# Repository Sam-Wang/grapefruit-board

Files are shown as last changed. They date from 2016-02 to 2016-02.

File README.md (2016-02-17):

uMeshFw Grapefruit board / debug platform
==============================================

During the last two years of sparse uMeshFw development I noticed that often a problem or a feature
cannot be properly simulated and tested. Most of the development was done on a qNode4 platform,
which (among the others) lacks support for many required peripherals and is not very debug-friendly.
It was (and still is) meant to be used in "production".

Therefore I decided to specify a new debug board / platform which should ease the development
of the uMeshFw firmware and uMesh protocol stack features.

Also, I had a feeling that qNodeX names are a bit boring.

This repository is a Work in Progress and is still incomplete. Full project description can be
found on the [project page](http://qyx.krtko.org/projects/umeshfw-grapefruit-board/)

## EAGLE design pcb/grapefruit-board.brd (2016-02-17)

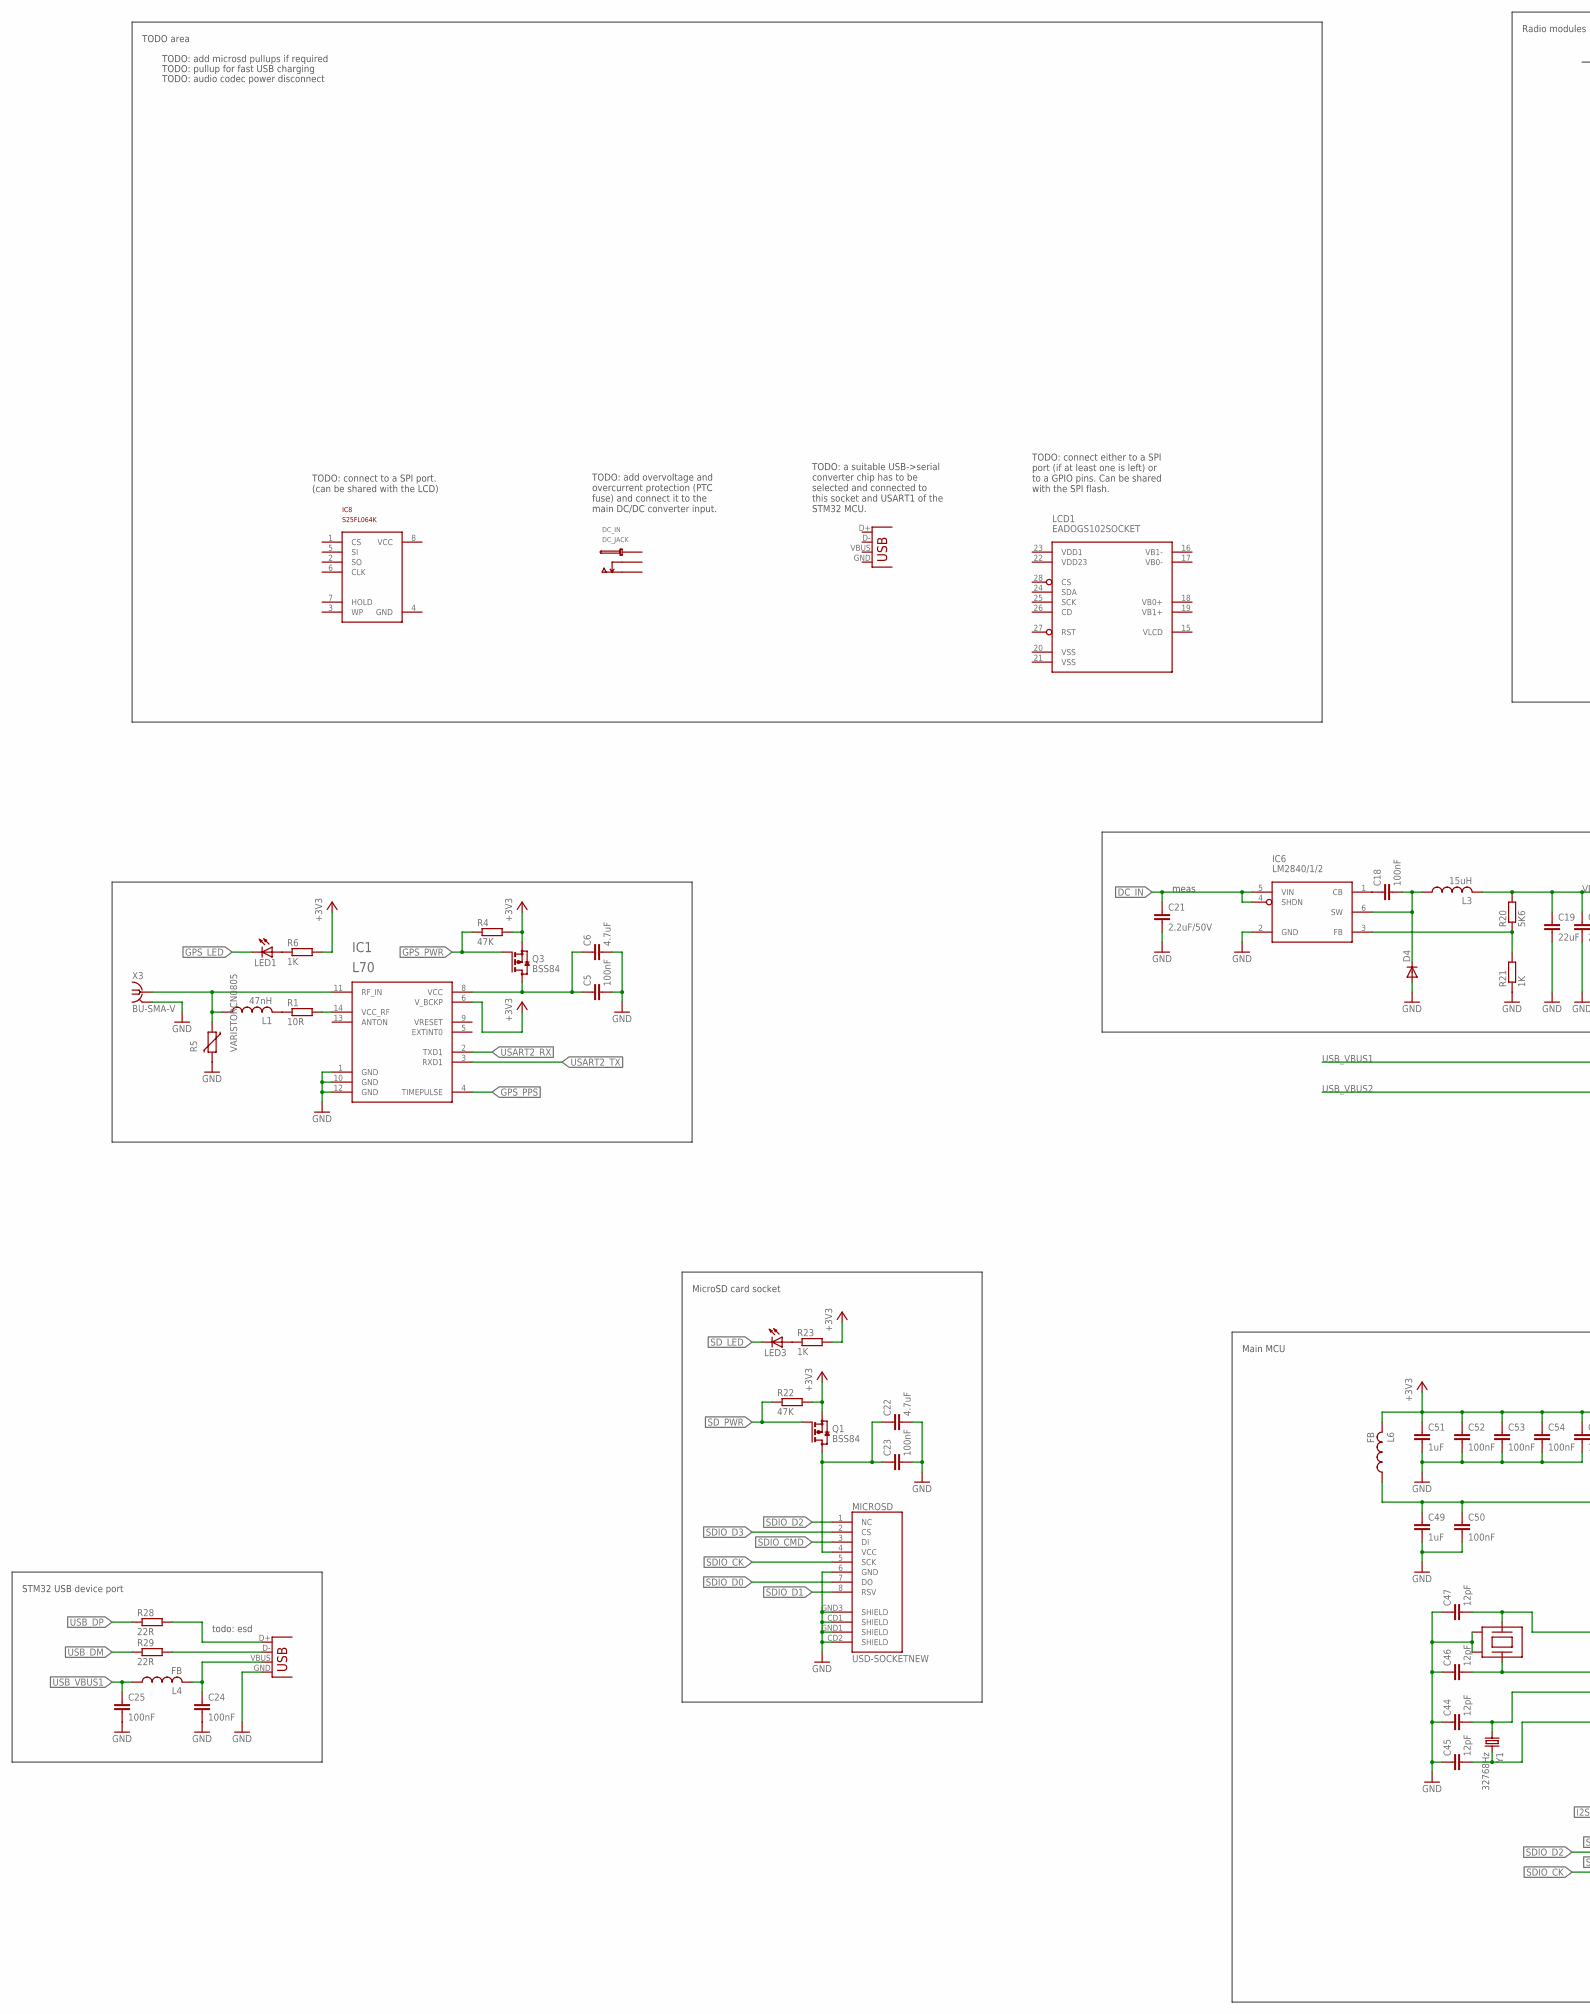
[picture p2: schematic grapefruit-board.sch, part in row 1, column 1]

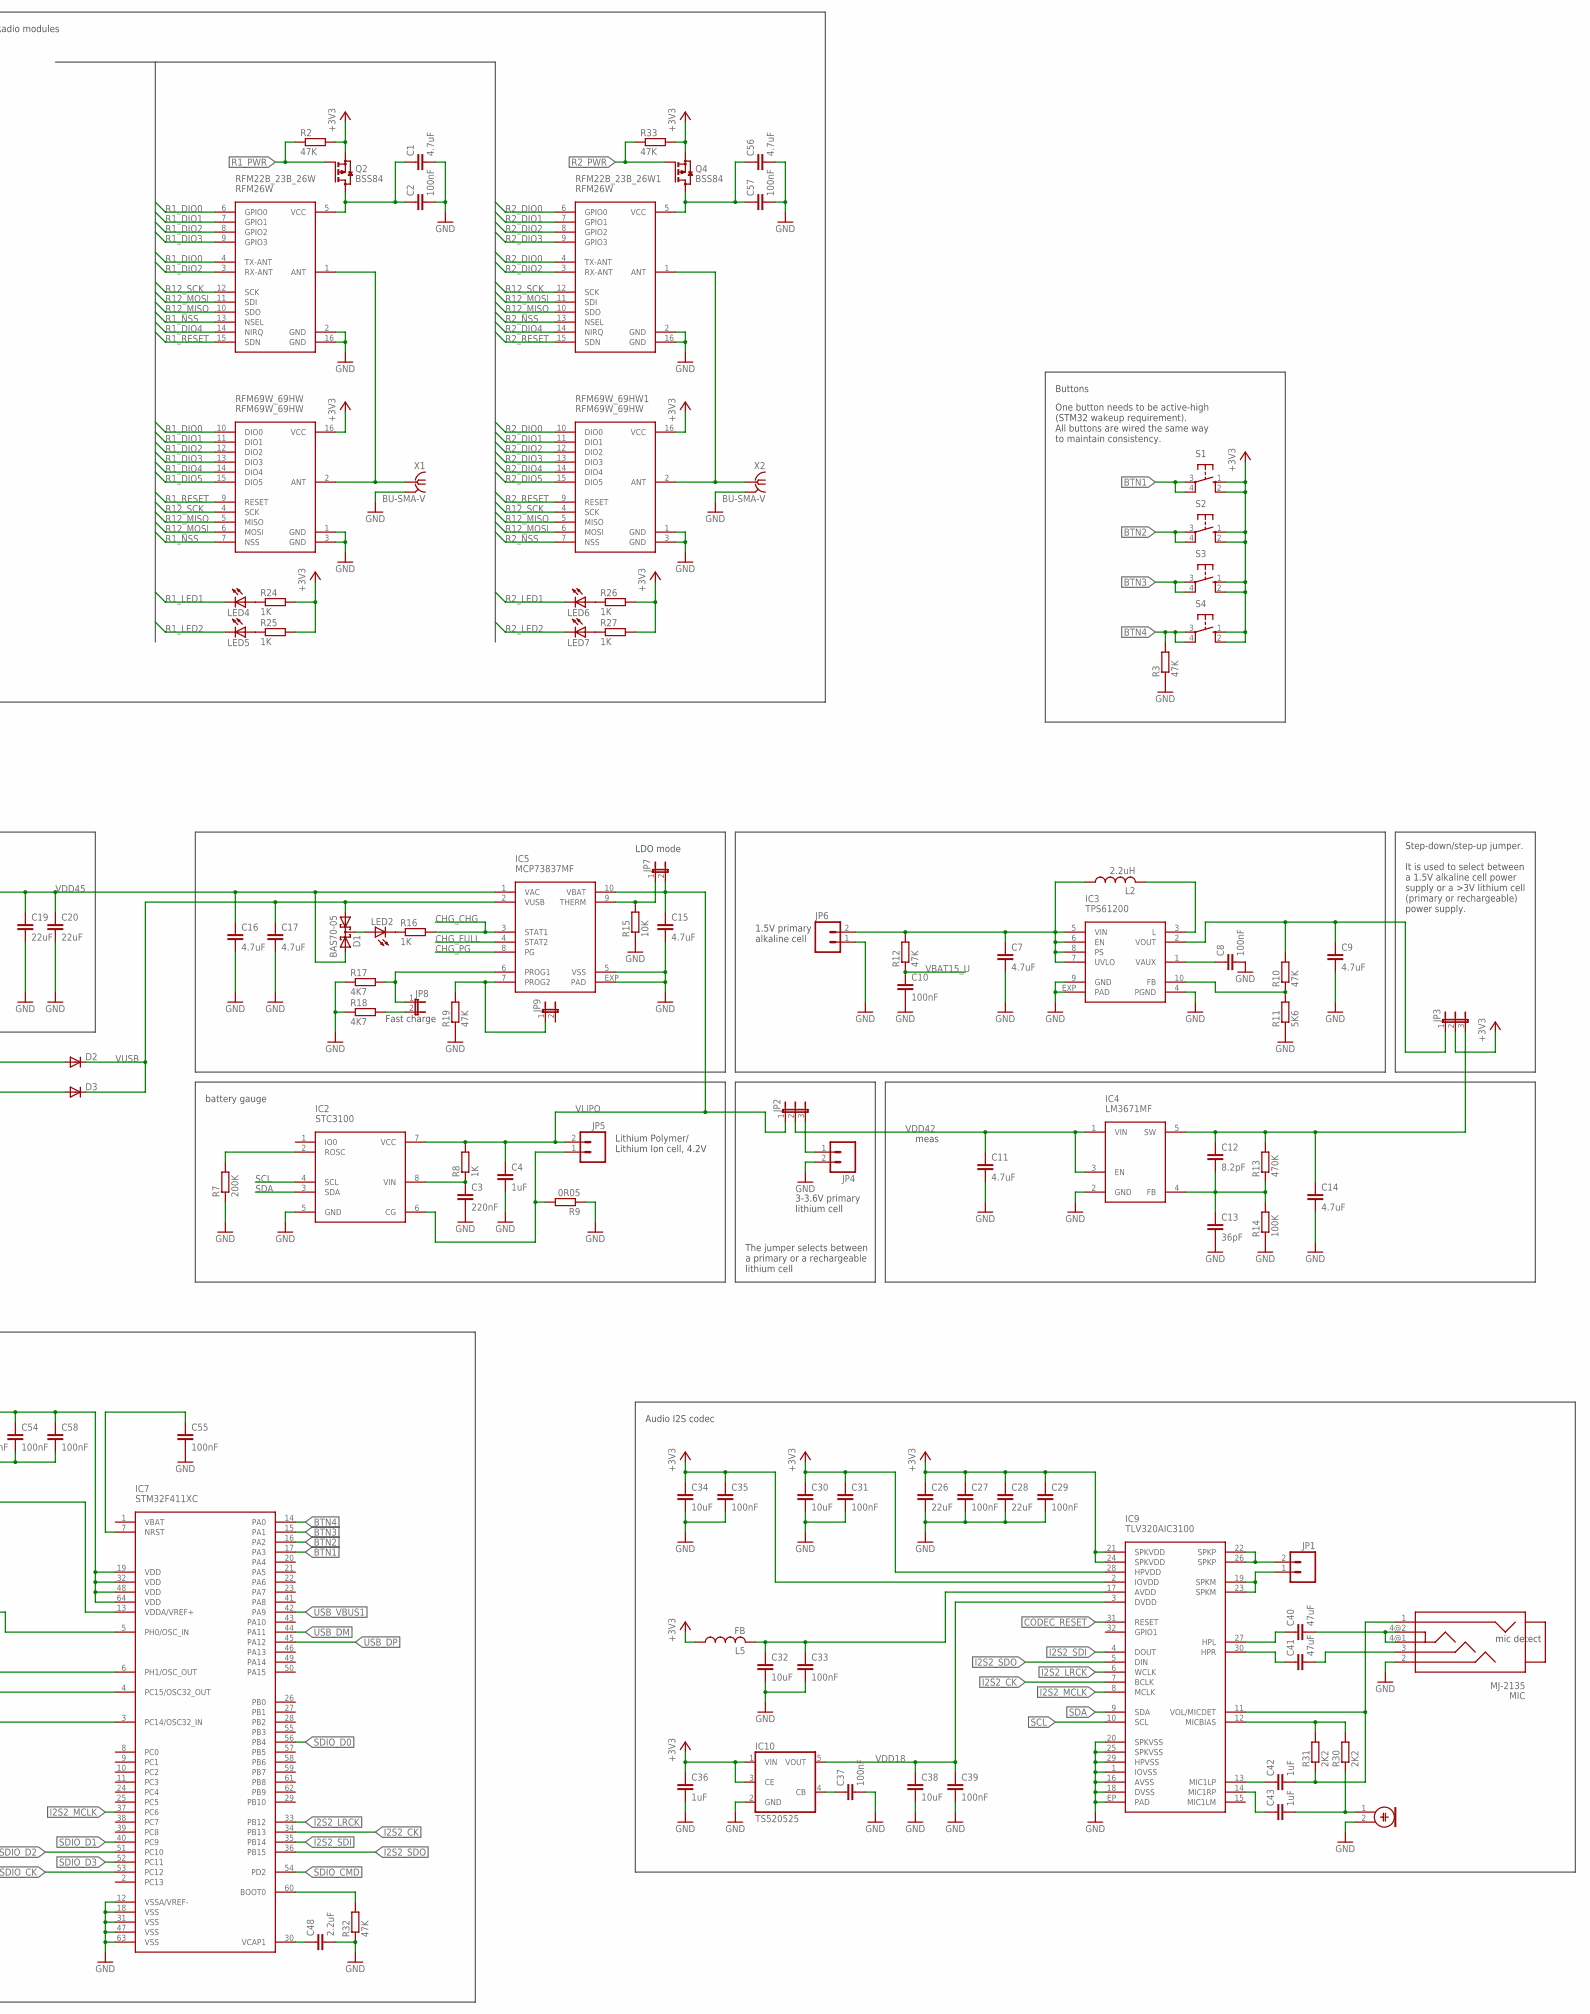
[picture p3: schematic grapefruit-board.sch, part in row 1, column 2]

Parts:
C1, C6, C7, C9, C11, C14, C15, C16, C17, C22, C56: 4.7uF; C0805
C2, C5, C8, C10, C18, C23, C24, C25, C27, C29, C31, C33, C35, C37, C39, C50, C52, C53, C54, C55, C57, C58: 100nF; C0603
C3: 220nF; C0603
C4, C42, C43, C49, C51: 1uF; C0603
C12: 8.2pF; C0603
C13: 36pF; C0603
C19, C20, C26, C28: 22uF; C1206
C21: 2.2uF/50V; C1206
C30, C32, C34, C38: 10uF; C1206
C36: 1uF; C0805
C40, C41: 47uF; C1206
C44, C45, C46, C47: 12pF; C0603
C48: 2.2uF; C0805
D1: BAS70-05; SOT23
D2, D3, D4: DIODE-MICROMELF-W; MICROMELF-W
DC_IN: DC_JACK
IC1: L70
IC2: STC3100; MSOP8
IC3: TPS61200; DFN10-3X3
IC4: LM3671MF; SOT23-5
IC5: MCP73837MF; DFN10-3X3
IC6: LM2840/1/2; SOT23-6
IC7: STM32F411XC; LQFP64
IC8: S25FL064K; SO-08M
IC9: TLV320AIC3100; QFN32
IC10: TS520525; SOT25
JP1, JP4, JP5, JP6: M02JST-PTH-2; JST-2-PTH
JP2, JP3: JP2E; JP2
JP7, JP8, JP9: JP1E; JP1
L1: 47nH; L2012C
L2: 2.2uH; L2012C
L3: 15uH; L3225M
L4, L5, L6: FB; L2012C
LCD1: EADOGS102SOCKET; EADOGS-SOCKET
LED1, LED2, LED3, LED4, LED5, LED6, LED7: LEDCHIP-LED0603; CHIP-LED0603
M1: ELECTRET_MICROPHON-WM-62PC/62PK; WM-62PC/62PK
MIC: MJ-2135; JACK_35_4POLE
MICROSD: USD-SOCKETNEW; MICRO-SD-SOCKET-PP
Q1, Q2, Q3, Q4: BSS84; SOT23
R1: 10R; R0603
R2, R3, R4, R10, R12, R19, R22, R32, R33: 47K; R0603
R5: VARISTORCN0805; CT/CN0805
R6, R8, R16, R21, R23, R24, R25, R26, R27: 1K; R0603
R7: 200K; R0603
R9: 0R05; R0805
R11, R20: 5K6; R0603
R13: 470K; R0603
R14: 100K; R0603
R15: 10K; R0603
R17, R18: 4K7; R0603
R28, R29: 22R; R0603
R30, R31: 2K2; R0603
RFM22B_23B_26W, RFM22B_23B_26W1: RFM26W; MODULE_16X16_16PIN
RFM69W_69HW, RFM69W_69HW1: RFM69W_69HW; MODULE_20X12_16PIN
S1, S2, S3, S4: 10-XX; B3F-10XX
U$1: XTAL-7M; XTAL_7M
X1, X2, X3: BU-SMA-V
X4, X5: USB-MICROB
Y1: 32768Hz; TC26H

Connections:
+3V3: C26.1, C27.1, C28.1, C29.1, C30.1, C31.1, C34.1, C35.1, C36.1, C51.1, C52.1, C53.1, C54.1, C58.1, IC1.6 (V_BCKP), IC7.19 (VDD), IC7.32 (VDD), IC7.48 (VDD), IC7.64 (VDD), IC9.2 (IOVDD), IC9.21 (SPKVDD), IC9.24 (SPKVDD), IC9.28 (HPVDD), IC10.1 (VIN), IC10.3 (CE), JP3.2, L5.1, L6.2, Q1.2 (S), Q2.2 (S), Q3.2 (S), Q4.2 (S), R2.2, R4.2, R6.2, R22.2, R23.2, R24.2, R25.2, R26.2, R27.2, R33.2, RFM69W_69HW.16 (VCC), RFM69W_69HW1.16 (VCC), S1.1 (S), S1.2 (S1), S2.1 (S), S2.2 (S1), S3.1 (S), S3.2 (S1), S4.1 (S), S4.2 (S1)
BTN1: IC7.17 (PA3), S1.3, S1.4 (P1)
BTN2: IC7.16 (PA2), S2.3, S2.4 (P1)
BTN3: IC7.15 (PA1), S3.3, S3.4 (P1)
BTN4: IC7.14 (PA0), R3.2, S4.3, S4.4 (P1)
CHG_CHG: IC5.3 (STAT1), R16.2
CHG_FULL: IC5.4 (STAT2)
CHG_PG: IC5.8 (PG)
CODEC_RESET: IC9.31 (RESET)
DC_IN: C21.1, IC6.4 (SHDN), IC6.5 (VIN)
GND: C1.2, C2.2, C3.2, C4.2, C5.2, C6.2, C7.2, C8.2, C9.2, C10.2, C11.2, C13.2, C14.2, C15.2, C16.2, C17.2, C19.2, C20.2, C21.2, C22.2, C23.2, C24.2, C25.2, C26.2, C27.2, C28.2, C29.2, C30.2, C31.2, C32.2, C33.2, C34.2, C35.2, C36.2, C37.2, C38.2, C39.2, C44.1, C45.1, C46.1, C47.1, C48.2, C49.2, C50.2, C51.2, C52.2, C53.2, C54.2, C55.2, C56.2, C57.2, C58.2, D4.A, IC1.1 (GND), IC1.10 (GND), IC1.12 (GND), IC2.5 (GND), IC3.4 (PGND), IC3.9 (GND), IC3.EXP (PAD), IC4.2 (GND), IC5.5 (VSS), IC5.EXP (PAD), IC6.2 (GND), IC7.12 (VSSA/VREF-), IC7.18 (VSS), IC7.31 (VSS), IC7.47 (VSS), IC7.63 (VSS), IC8.4 (GND), IC9.1 (IOVSS), IC9.16 (AVSS), IC9.18 (DVSS), IC9.20 (SPKVSS), IC9.25 (SPKVSS), IC9.29 (HPVSS), IC9.EP (PAD), IC10.2 (GND), JP4.2, JP6.1, M1.2, MIC.2, MICROSD.6 (GND), MICROSD.CD1 (SHIELD), MICROSD.CD2 (SHIELD), MICROSD.GND1 (SHIELD), MICROSD.GND3 (SHIELD), R3.1, R5.2, R7.1, R9.1, R11.1, R14.1, R15.1, R17.1, R18.1, R19.1, R21.1, R32.1, RFM22B_23B_26W.2 (GND), RFM22B_23B_26W.16 (GND), RFM22B_23B_26W1.2 (GND), RFM22B_23B_26W1.16 (GND), RFM69W_69HW.1 (GND), RFM69W_69HW.3 (GND), RFM69W_69HW1.1 (GND), RFM69W_69HW1.3 (GND), U$1.2 (G1), U$1.4 (G2), X1.2, X1.3 (2), X1.4 (2), X1.5 (2), X2.2, X2.3 (2), X2.4 (2), X2.5 (2), X3.2, X3.3 (2), X3.4 (2), X3.5 (2), X4.GND
GPS_LED: LED1.C
GPS_PPS: IC1.4 (TIMEPULSE)
GPS_PWR: Q3.1 (G), R4.1
I2S2_CK: IC7.34 (PB13), IC9.7 (BCLK)
I2S2_LRCK: IC7.33 (PB12), IC9.6 (WCLK)
I2S2_MCLK: IC7.37 (PC6), IC9.8 (MCLK)
I2S2_SDI: IC7.35 (PB14), IC9.4 (DOUT)
I2S2_SDO: IC7.36 (PB15), IC9.5 (DIN)
unnamed: RFM22B_23B_26W1.1 (ANT), RFM69W_69HW1.2 (ANT), X2.1
unnamed: RFM22B_23B_26W.1 (ANT), RFM69W_69HW.2 (ANT), X1.1
unnamed: L1.2, R1.1
unnamed: IC1.11 (RF_IN), L1.1, R5.1, X3.1
unnamed: IC1.14 (VCC_RF), R1.2
unnamed: C1.1, C2.1, Q2.3 (D), RFM22B_23B_26W.5 (VCC)
unnamed: LED1.A, R6.1
unnamed: C5.1, C6.1, IC1.8 (VCC), Q3.3 (D)
unnamed: C7.1, IC3.5 (VIN), IC3.6 (EN), IC3.7 (UVLO), IC3.8 (PS), JP6.2, L2.1, R12.2
unnamed: JP2.3, JP4.1
unnamed: IC2.6 (CG), JP5.1, R9.2
unnamed: IC5.9 (THERM), JP7.1, R15.2
unnamed: IC5.6 (PROG1), JP8.1, R17.2
unnamed: C12.1, C14.1, IC4.5 (SW), JP3.3, R13.2
unnamed: C3.1, IC2.8 (VIN), R8.1
unnamed: C8.1, IC3.1 (VAUX)
unnamed: IC2.2 (ROSC), R7.2
unnamed: C9.1, IC3.2 (VOUT), JP3.1, R10.2
unnamed: IC3.3 (L), L2.2
unnamed: C12.2, C13.1, IC4.4 (FB), R13.1, R14.2
unnamed: IC3.10 (FB), R10.1, R11.2
unnamed: JP8.2, R18.2
unnamed: LED2.C, R16.1
unnamed: D1.3 (C), LED2.A
unnamed: IC5.7 (PROG2), JP9.1, R19.2
unnamed: C18.1, IC6.1 (CB)
unnamed: C18.2, D4.C, IC6.6 (SW), L3.1
unnamed: IC6.3 (FB), R20.1, R21.2
unnamed: C22.1, C23.1, MICROSD.4 (VCC), Q1.3 (D)
unnamed: LED3.A, R23.1
unnamed: LED4.A, R24.1
unnamed: LED5.A, R25.1
unnamed: LED6.A, R26.1
unnamed: LED7.A, R27.1
unnamed: R28.2, X4.D+
unnamed: R29.2, X4.D-
unnamed: C24.1, L4.2, X4.VBUS
unnamed: C43.1, IC9.14 (MIC1RP)
unnamed: C32.1, C33.1, IC9.17 (AVDD), L5.2
unnamed: C37.1, IC10.4 (CB)
unnamed: C40.2, MIC.4@1 (4), MIC.4@2 (4)
unnamed: C41.2, MIC.3
unnamed: C41.1, IC9.30 (HPR)
unnamed: C40.1, IC9.27 (HPL)
unnamed: C44.2, IC7.4 (PC15/OSC32_OUT), Y1.1
unnamed: C42.1, IC9.13 (MIC1LP)
unnamed: C42.2, IC9.11 (VOL/MICDET), MIC.1, R31.1
unnamed: C43.2, M1.1, R30.1
unnamed: IC9.12 (MICBIAS), R30.2, R31.2
unnamed: IC9.22 (SPKP), IC9.26 (SPKP), JP1.2
unnamed: IC9.19 (SPKM), IC9.23 (SPKM), JP1.1
unnamed: C45.2, IC7.3 (PC14/OSC32_IN), Y1.2
unnamed: C55.1, IC7.7 (NRST)
unnamed: C47.2, IC7.5 (PH0/OSC_IN), U$1.1
unnamed: C46.2, IC7.6 (PH1/OSC_OUT), U$1.3 (2)
unnamed: C56.1, C57.1, Q4.3 (D), RFM22B_23B_26W1.5 (VCC)
unnamed: IC7.60 (BOOT0), R32.2
unnamed: C48.1, IC7.30 (VCAP1)
unnamed: C49.1, C50.1, IC7.13 (VDDA/VREF+), L6.1
R1_DIO0: RFM22B_23B_26W.4 (TX-ANT), RFM22B_23B_26W.6 (GPIO0), RFM69W_69HW.10 (DIO0)
R1_DIO1: RFM22B_23B_26W.7 (GPIO1), RFM69W_69HW.11 (DIO1)
R1_DIO2: RFM22B_23B_26W.3 (RX-ANT), RFM22B_23B_26W.8 (GPIO2), RFM69W_69HW.12 (DIO2)
R1_DIO3: RFM22B_23B_26W.9 (GPIO3), RFM69W_69HW.13 (DIO3)
R1_DIO4: RFM22B_23B_26W.14 (NIRQ), RFM69W_69HW.14 (DIO4)
R1_DIO5: RFM69W_69HW.15 (DIO5)
R1_LED1: LED4.C
R1_LED2: LED5.C
R1_NSS: RFM22B_23B_26W.13 (NSEL), RFM69W_69HW.7 (NSS)
R1_PWR: Q2.1 (G), R2.1
R1_RESET: RFM22B_23B_26W.15 (SDN), RFM69W_69HW.9 (RESET)
R2_DIO0: RFM22B_23B_26W1.4 (TX-ANT), RFM22B_23B_26W1.6 (GPIO0), RFM69W_69HW1.10 (DIO0)
R2_DIO1: RFM22B_23B_26W1.7 (GPIO1), RFM69W_69HW1.11 (DIO1)
R2_DIO2: RFM22B_23B_26W1.3 (RX-ANT), RFM22B_23B_26W1.8 (GPIO2), RFM69W_69HW1.12 (DIO2)
R2_DIO3: RFM22B_23B_26W1.9 (GPIO3), RFM69W_69HW1.13 (DIO3)
R2_DIO4: RFM22B_23B_26W1.14 (NIRQ), RFM69W_69HW1.14 (DIO4)
R2_DIO5: RFM69W_69HW1.15 (DIO5)
R2_LED1: LED6.C
R2_LED2: LED7.C
R2_NSS: RFM22B_23B_26W1.13 (NSEL), RFM69W_69HW1.7 (NSS)
R2_PWR: Q4.1 (G), R33.1
R2_RESET: RFM22B_23B_26W1.15 (SDN), RFM69W_69HW1.9 (RESET)
R12_MISO: RFM22B_23B_26W.10 (SDO), RFM22B_23B_26W1.10 (SDO), RFM69W_69HW.5 (MISO), RFM69W_69HW1.5 (MISO)
R12_MOSI: RFM22B_23B_26W.11 (SDI), RFM22B_23B_26W1.11 (SDI), RFM69W_69HW.6 (MOSI), RFM69W_69HW1.6 (MOSI)
R12_SCK: RFM22B_23B_26W.12 (SCK), RFM22B_23B_26W1.12 (SCK), RFM69W_69HW.4 (SCK), RFM69W_69HW1.4 (SCK)
SCL: IC2.4 (SCL), IC9.10 (SCL)
SDA: IC2.3 (SDA), IC9.9 (SDA)
SDIO_CK: IC7.53 (PC12), MICROSD.5 (SCK)
SDIO_CMD: IC7.54 (PD2), MICROSD.3 (DI)
SDIO_D0: IC7.56 (PB4), MICROSD.7 (DO)
SDIO_D1: IC7.40 (PC9), MICROSD.8 (RSV)
SDIO_D2: IC7.51 (PC10), MICROSD.1 (NC)
SDIO_D3: IC7.52 (PC11), MICROSD.2 (CS)
SD_LED: LED3.C
SD_PWR: Q1.1 (G), R22.1
USART2_RX: IC1.2 (TXD1)
USART2_TX: IC1.3 (RXD1)
USB_DM: IC7.44 (PA11), R29.1
USB_DP: IC7.45 (PA12), R28.1
USB_VBUS1: C25.1, D2.A, IC7.42 (PA9), L4.1
USB_VBUS2: D3.A
VBAT15_U: C10.1, R12.1
VCC: IC8.8 (VCC)
VDD18: C38.1, C39.1, IC9.3 (DVDD), IC10.5 (VOUT)
VDD42: C11.1, IC4.1 (VIN), IC4.3 (EN), JP2.2
VDD45: C16.1, C19.1, C20.1, D1.2 (A2), IC5.1 (VAC), L3.2, R20.2
VLIPO: C4.1, C15.1, IC2.7 (VCC), IC5.10 (VBAT), JP2.1, JP5.2, JP7.2, R8.2
VUSB: C17.1, D1.1 (A1), D2.C, D3.C, IC5.2 (VUSB)

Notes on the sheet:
mic detect
battery gauge
Lithium Polymer/ Lithium Ion cell, 4.2V
3-3.6V primary lithium cell
1.5V primary alkaline cell
meas
Step-down/step-up jumper. It is used to select between a 1.5V alkaline cell power supply or a >3V lithium cell (primary or rechargeable) power supply.
The jumper selects between a primary or a rechargeable lithium cell
TODO: pullup for fast USB charging
LDO mode
Fast charge
todo: esd
TODO: audio codec power disconnect
Buttons
One button needs to be active-high (STM32 wakeup requirement). All buttons are wired the same way to maintain consistency.
TODO area
TODO: add overvoltage and overcurrent protection (PTC fuse) and connect it to the main DC/DC converter input.
TODO: a suitable USB->serial converter chip has to be selected and connected to this socket and USART1 of the STM32 MCU.
TODO: connect either to a SPI port (if at least one is left) or to a GPIO pins. Can be shared with the SPI flash.
TODO: connect to a SPI port. (can be shared with the LCD)
STM32 USB device port
MicroSD card socket
TODO: add microsd pullups if required
Main MCU
Audio I2S codec
Radio modules

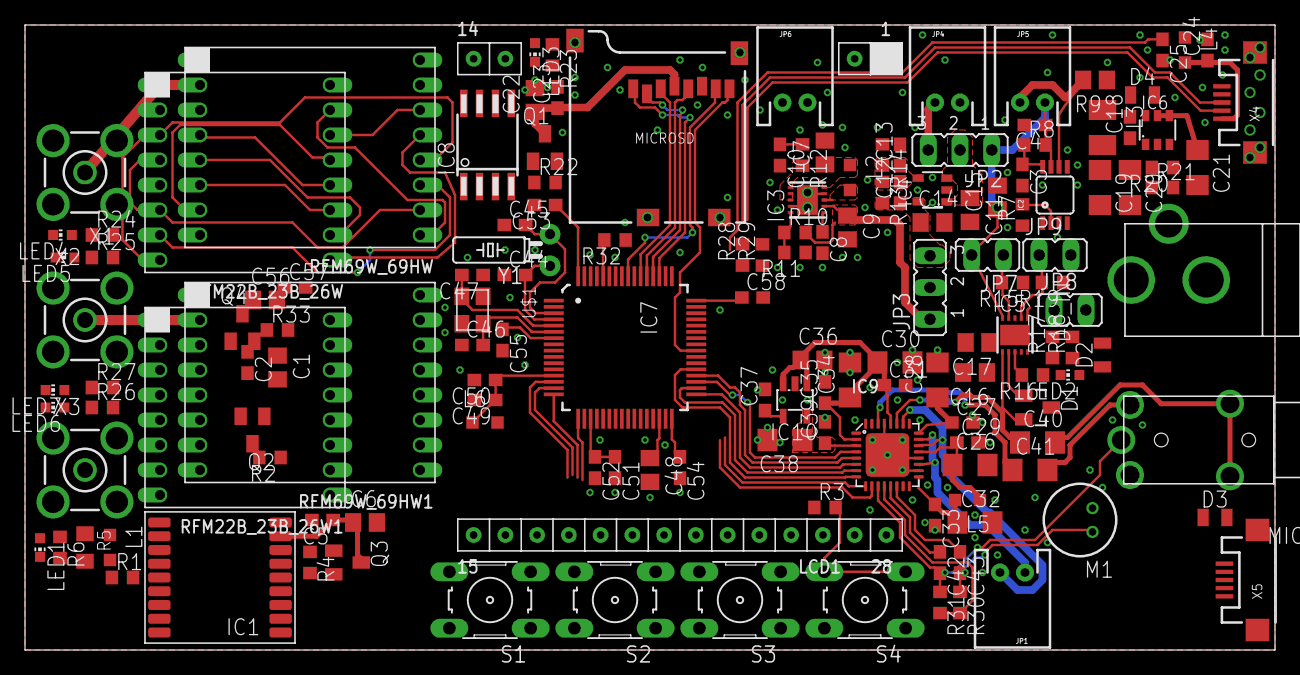
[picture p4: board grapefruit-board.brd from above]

Board: 2 copper layers, 100.0 x 50.0 mm, 151 parts (0 on the bottom side), 110 nets.

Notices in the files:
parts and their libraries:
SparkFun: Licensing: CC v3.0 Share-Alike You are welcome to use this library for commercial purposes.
